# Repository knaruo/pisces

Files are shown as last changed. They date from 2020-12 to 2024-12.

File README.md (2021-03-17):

# pisces
Pisces - Tiny Split Keyboard

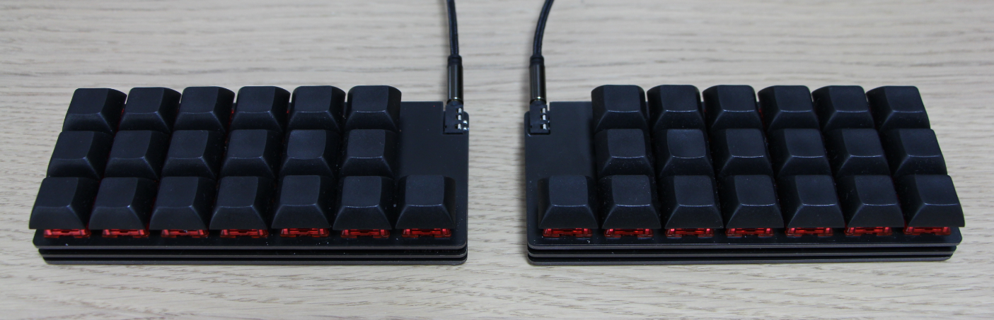
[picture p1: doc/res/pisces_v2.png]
Pisces V1


# Concept

* Ortholinear
  * 3 rows \* 6 columns + 1 thumb key, total 38 keys
* Key switch hot-swap capable
  * Supports Kailh PCB socket for MX
* Thin design
  * Only supports SMT diodes (1N4148W)

# BOM list

Number of components in the following bill of material table is for one hand.

**Here are the mandatory items:**
| Name | Parts id | Number | Note |
| --- | --- | --- | --- |
| Diode | 1N4148W | 19 | Availaable from [here](https://akizukidenshi.com/catalog/g/gI-07084/) |
| ATmega32U2 | - | 1 | |
| TRRS jack | PRT-12639 | 1 | Available from [here](https://www.sengoku.co.jp/mod/sgk_cart/detail.php?code=EEHD-4VML) |
| TRRS cable | - | 1 | |
| Reset Switch | TVAF06-A020B-R | 1 | Available from [here](https://akizukidenshi.com/catalog/g/gP-14888/) |

**For Cherry MX profile:**

| Name | Parts id | Number | Note |
| --- | --- | --- | --- |
| Socket (MX) | CPG151101S11 | 19 | [here](https://kbdfans.com/collections/switches/products/mechanical-keyboard-switches-kailh-pcb-socket) |
| Spacer (M2 7mm)  | ARB-2007E | 6 | [here](https://www.hirosugi-net.co.jp/shop/g/g2392/) |
| Thread (M2 3mm)  | - | 12 | [here for example..](https://www.amazon.co.jp/dp/B083DR1YQL/ref=cm_sw_em_r_mt_dp_sWb6FbA93WCSS) |

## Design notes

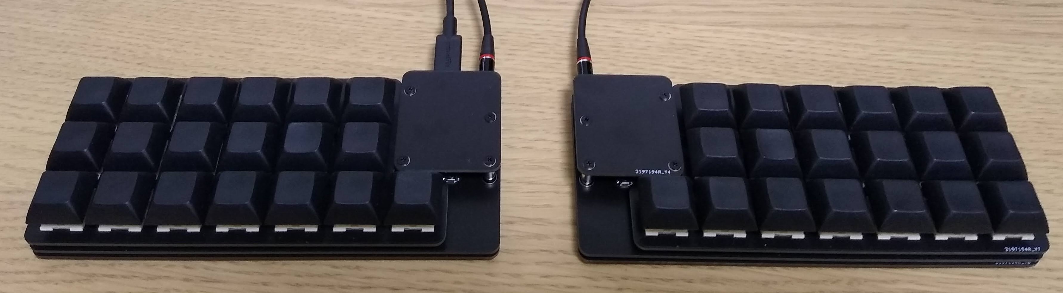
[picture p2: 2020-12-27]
doc/res/pisces_v1_look.jpg

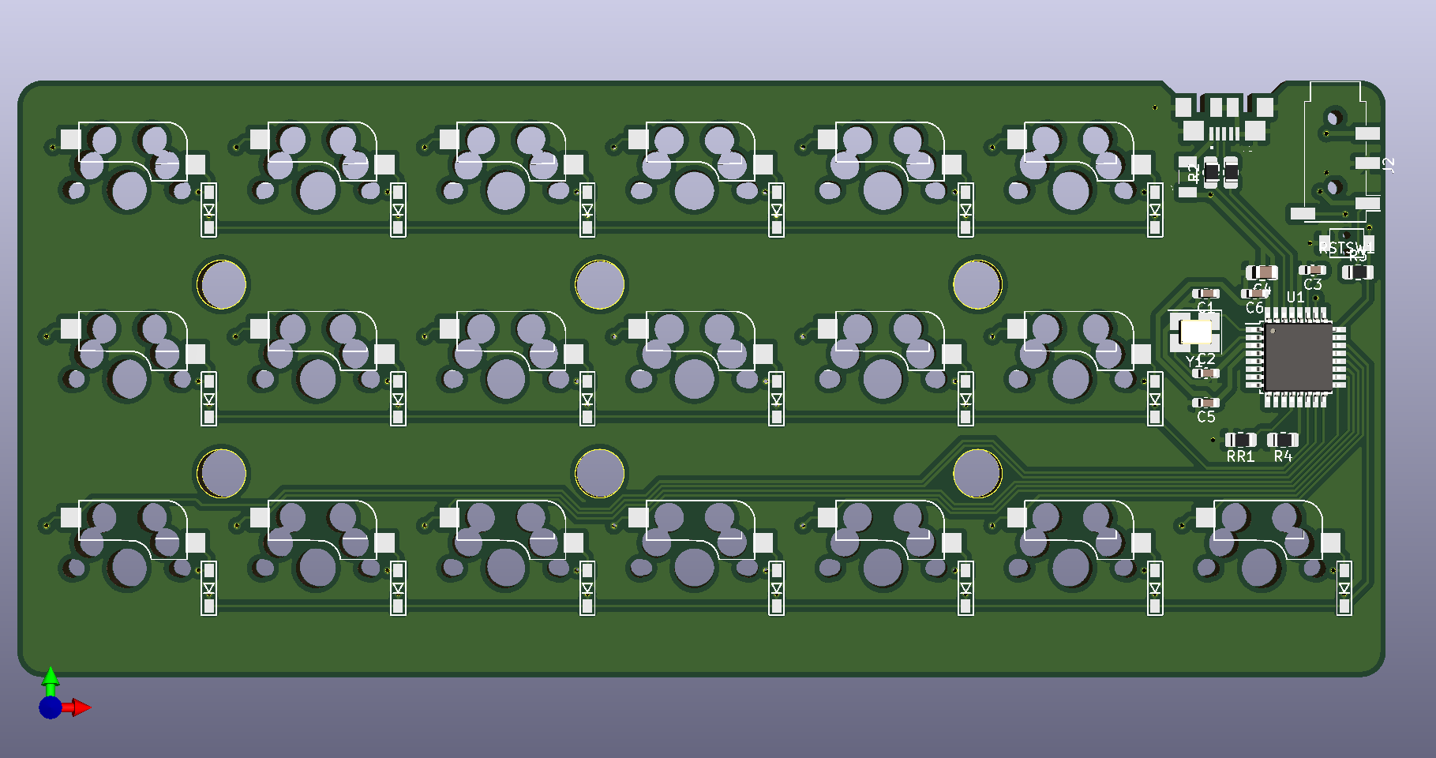
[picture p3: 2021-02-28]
doc/res/pisces_v2_pcb.png

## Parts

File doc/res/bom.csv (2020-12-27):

Name | Parts id | Number | Note
Diode | 1N4148W | 19 | Availaable from [here](https://akizukidenshi.com/catalog/g/gI-07084/)
ProMicro | - | 1 | Available from [here](https://talpkeyboard.stores.jp/items/5b24504ba6e6ee7ec60063e3)
TRRS jack | PRT-12639 | 1 | Available from [here](https://www.sengoku.co.jp/mod/sgk_cart/detail.php?code=EEHD-4VML)
TRRS cable | - | 1
Reset Switch | TVAF06-A020B-R | 1 | Available from [here](https://akizukidenshi.com/catalog/g/gP-14888/)
LED | WS2812B | 1 | Available from [here](https://akizukidenshi.com/catalog/g/gI-07915/)
Socket (MX) | CPG151101S11 | 19 | [here](https://kbdfans.com/collections/switches/products/mechanical-keyboard-switches-kailh-pcb-socket)
Spacer (M2 4mm) | ARB-2004E | 6 | [here](https://www.hirosugi-net.co.jp/shop/g/g2386/)
Spacer (M2 7mm) | ARB-2007E | 6 | [here](https://www.hirosugi-net.co.jp/shop/g/g2392/)
Spacer (M2 12mm) | ARB-2012E | 4 | [here](https://www.hirosugi-net.co.jp/shop/g/g2400/)
Thread (M2 3mm) | - | 20 | [here for example..](https://www.amazon.co.jp/dp/B083DR1YQL/ref=cm_sw_em_r_mt_dp_sWb6FbA93WCSS)
Socket (ChocV1) | CPG135001S30 | 19 | [here](https://kbdfans.com/collections/switches/products/mechanical-keyboard-low-profile-switches-kailh-pcb-socket-cpg135001s30)

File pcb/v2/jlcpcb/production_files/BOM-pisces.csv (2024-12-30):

Comment | Designator | Footprint | LCSC | Quantity
0.1u | C3,C6 | C_0402_1005Metric | C1546 | 2
22p | C1,C2 | C_0402_1005Metric | C1555 | 2
1u | C5 | C_0603_1608Metric | C15849 | 1
10u | C4 | C_0805_2012Metric | C15850 | 1
USB_C | J1 | USB_C_Receptacle_XKB_U262-16XN-4BVC11 | C165948 | 1
5.1k | R1,R2 | R_0603_1608Metric | C23186 | 2
10k | R3,R4 | R_0603_1608Metric | C25804 | 2
5.1k | R5,R6 | R_0402_1005Metric | C25905 | 2
Crystal_GND24_Small | Y1 | Crystal_SMD_SeikoEpson_FA238-4Pin_3.2x2.5mm | C362342 | 1
Polyfuse_Small | F1 | RESC1206X70N | C720075 | 1

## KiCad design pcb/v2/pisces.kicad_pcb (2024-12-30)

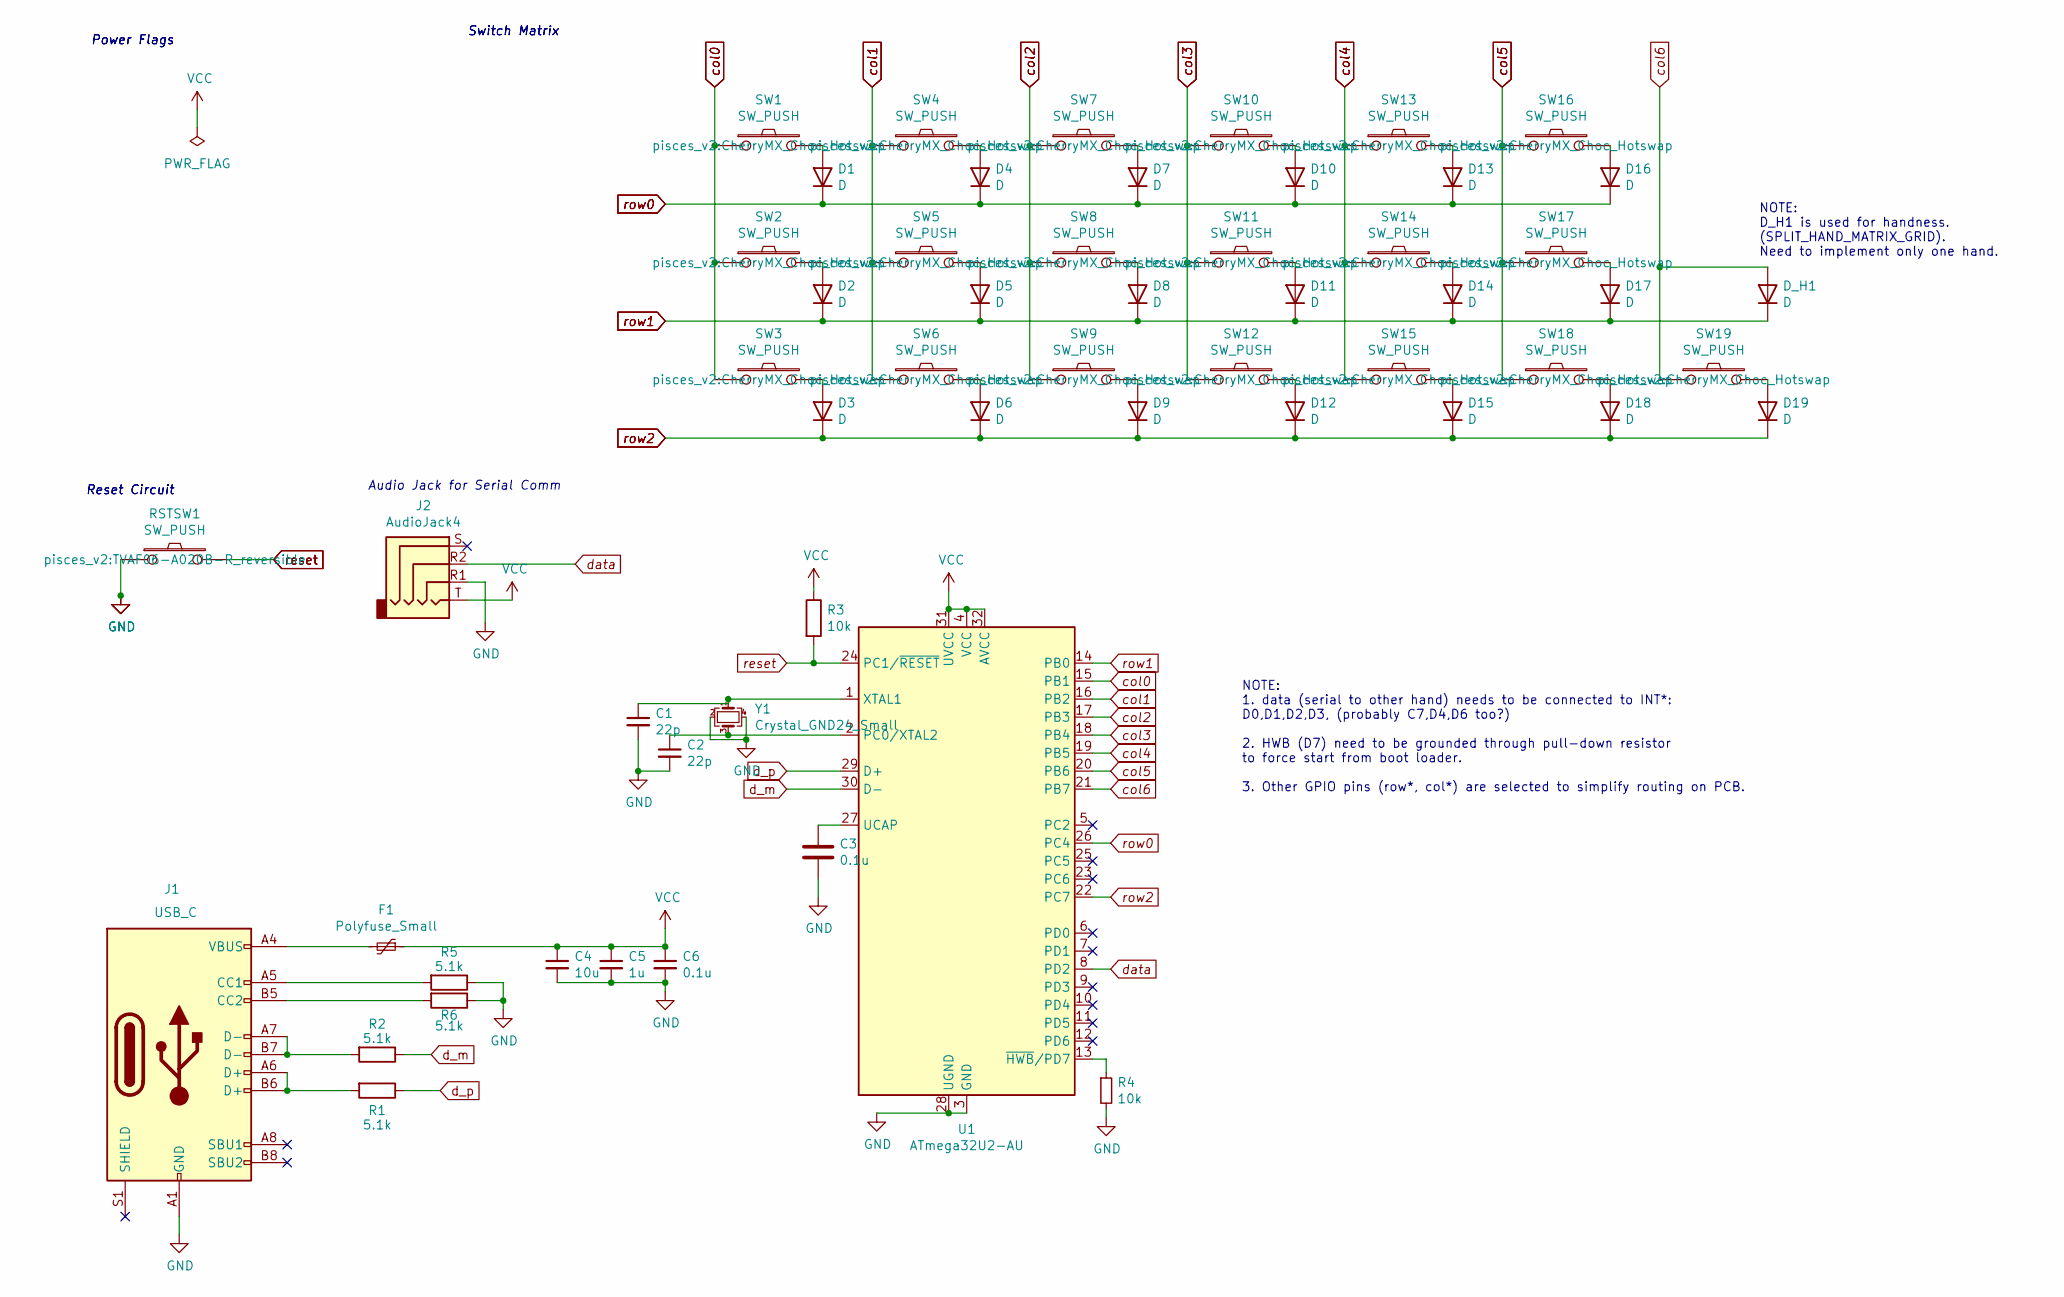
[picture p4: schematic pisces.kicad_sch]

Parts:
C1, C2: 22p; C_0402_1005Metric
C3, C6: 0.1u; C_0402_1005Metric
C4: 10u; C_0805_2012Metric
C5: 1u; C_0603_1608Metric
D1, D2, D3, D4, D5, D6, D7, D8, D9, D10, D11, D12, D13, D14, D15, D16, D17, D18, D19: D; D3_SMD
D_H1: D; D3_SMD
F1: Polyfuse_Small; RESC1206X70N
J1: USB_C; USB_C_Receptacle_XKB_U262-16XN-4BVC11
J2: AudioJack4; Jack_3.5mm_PJ320D_Horizontal_reversible
R1, R2: 5.1k; R_0603_1608Metric
R3, R4: 10k; R_0603_1608Metric
R5, R6: 5.1k; R_0402_1005Metric
RSTSW1: SW_PUSH; TVAF06-A020B-R_reversible
SW1, SW2, SW3, SW4, SW5, SW6, SW7, SW8, SW9, SW10, SW11, SW12, SW13, SW14, SW15, SW16, SW17, SW18, SW19: SW_PUSH; CherryMX_Choc_Hotswap
U1: ATmega32U2-AU; TQFP-32_7x7mm_P0.8mm
Y1: Crystal_GND24_Small; Crystal_SMD_SeikoEpson_FA238-4Pin_3.2x2.5mm

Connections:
GND: C1.2, C2.2, C3.2, C4.2, C5.2, C6.2, J1.A1 (GND), J1.A12 (GND), J1.B1 (GND), J1.B12 (GND), J2.R1, R4.2, R5.1, R6.1, RSTSW1.1, U1.3 (GND), U1.28 (UGND), Y1.2, Y1.4
unnamed: D1.2 (A), SW1.2
unnamed: D2.2 (A), SW2.2
unnamed: D3.2 (A), SW3.2
unnamed: D4.2 (A), SW4.2
unnamed: D5.2 (A), SW5.2
unnamed: D6.2 (A), SW6.2
unnamed: D7.2 (A), SW7.2
unnamed: D8.2 (A), SW8.2
unnamed: D9.2 (A), SW9.2
unnamed: D10.2 (A), SW10.2
unnamed: D11.2 (A), SW11.2
unnamed: D12.2 (A), SW12.2
unnamed: D13.2 (A), SW13.2
unnamed: D14.2 (A), SW14.2
unnamed: D15.2 (A), SW15.2
unnamed: D16.2 (A), SW16.2
unnamed: D17.2 (A), SW17.2
unnamed: D18.2 (A), SW18.2
unnamed: D19.2 (A), SW19.2
unnamed: F1.2, J1.A4 (VBUS), J1.A9 (VBUS), J1.B4 (VBUS), J1.B9 (VBUS)
unnamed: J1.A5 (CC1), R5.2
unnamed: J1.B5 (CC2), R6.2
unnamed: J1.A6 (D+), J1.B6 (D+), R1.2
unnamed: J1.A7 (D-), J1.B7 (D-), R2.2
unnamed: C2.1, U1.2 (PC0/XTAL2), Y1.3
unnamed: C3.1, U1.27 (UCAP)
unnamed: C1.1, U1.1 (XTAL1), Y1.1
unnamed: R4.1, U1.13 (~HWB/PD7)
VCC: C4.1, C5.1, C6.1, F1.1, J2.T, R3.1, U1.4 (VCC), U1.31 (UVCC), U1.32 (AVCC)
col0: SW1.1, SW2.1, SW3.1, U1.15 (PB1)
col1: SW4.1, SW5.1, SW6.1, U1.16 (PB2)
col2: SW7.1, SW8.1, SW9.1, U1.17 (PB3)
col3: SW10.1, SW11.1, SW12.1, U1.18 (PB4)
col4: SW13.1, SW14.1, SW15.1, U1.19 (PB5)
col5: SW16.1, SW17.1, SW18.1, U1.20 (PB6)
col6: D_H1.2 (A), SW19.1, U1.21 (PB7)
d_m: R2.1, U1.30 (D-)
d_p: R1.1, U1.29 (D+)
data: J2.R2, U1.8 (PD2)
reset: R3.2, RSTSW1.2, U1.24 (PC1/~RESET)
row0: D1.1 (K), D4.1 (K), D7.1 (K), D10.1 (K), D13.1 (K), D16.1 (K), U1.26 (PC4)
row1: D2.1 (K), D5.1 (K), D8.1 (K), D11.1 (K), D14.1 (K), D17.1 (K), D_H1.1 (K), U1.14 (PB0)
row2: D3.1 (K), D6.1 (K), D9.1 (K), D12.1 (K), D15.1 (K), D18.1 (K), D19.1 (K), U1.22 (PC7)

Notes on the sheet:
Audio Jack for Serial Comm
Power Flags
Switch Matrix
Reset Circuit
NOTE: D_H1 is used for handness. (SPLIT_HAND_MATRIX_GRID). Need to implement only one hand.
NOTE: 1. data (serial to other hand) needs to be connected to INT*: D0,D1,D2,D3, (probably C7,D4,D6 too?) 2. HWB (D7) need to be grounded through pull-down resistor to force start from boot loader. 3. Other GPIO pins (row*, col*) are selected to simplify routing on PCB.

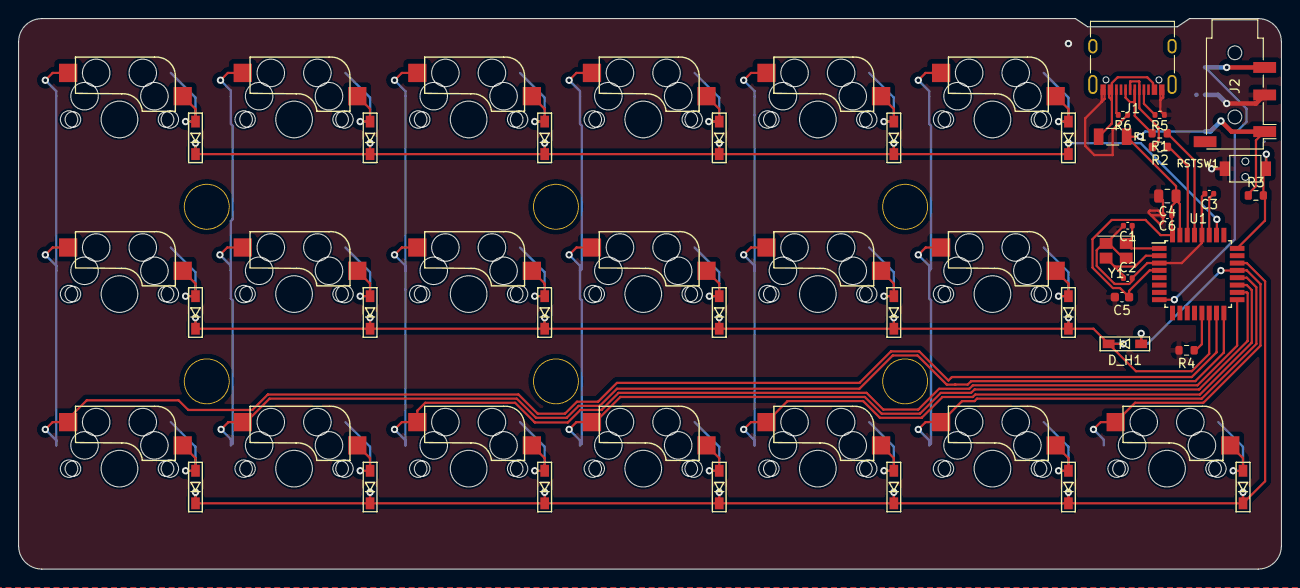
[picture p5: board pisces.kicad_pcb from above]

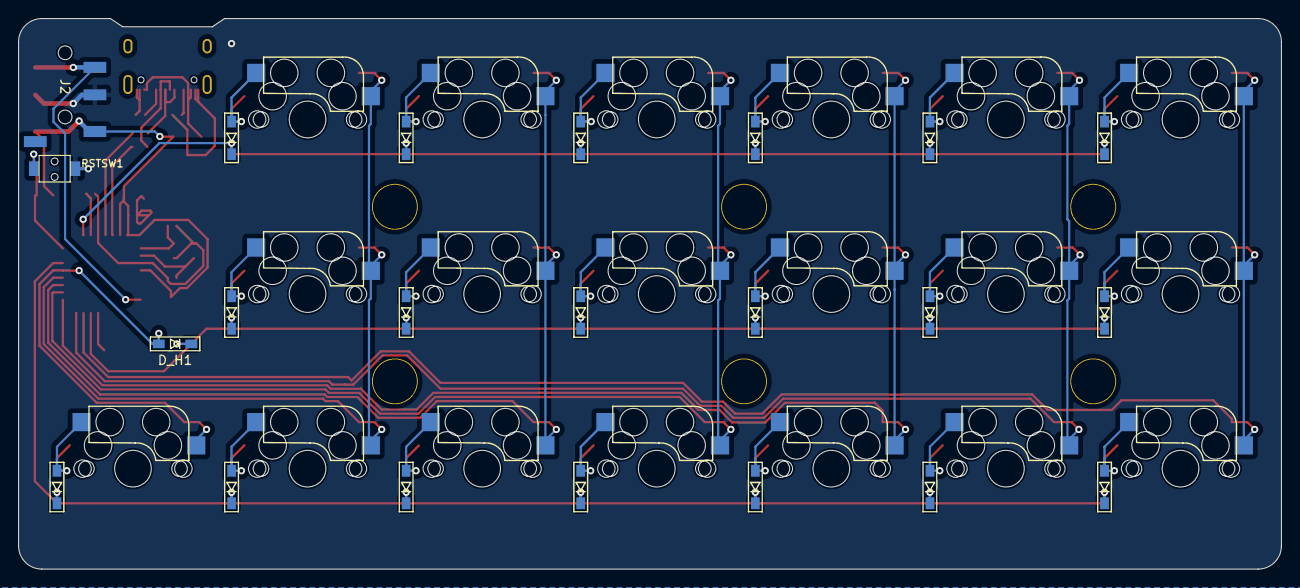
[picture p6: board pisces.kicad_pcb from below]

Board: 2 copper layers, 137.8 x 60.1 mm, 63 parts (19 on the bottom side), 44 nets.

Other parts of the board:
HOLE1, HOLE2, HOLE7, HOLE8, HOLE13, HOLE14: Val**; HOLE

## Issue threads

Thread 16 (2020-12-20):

Fix LED footprint for right-hand side.

knaruo, 2020-12-20:
LED footprint was not correct.

knaruo, 2021-02-28:
Dropped this issue - V1 design is not going to be supported

Closed 2021-02-28.

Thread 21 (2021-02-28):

Fix on V2.0 PCB design

knaruo, 2021-02-28:
- Add terminator resistor to serial comm
- Pull up, pull down resistors to determine right or left hand

knaruo, 2021-03-17:
Done in #22
Pull up/Pull down resistor is not used to determine the handness. Instead, SPLIT_HAND_MATRIX_GRID in QMK feature is used.

Closed 2021-03-17.

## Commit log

2020-12-04 Issue1 copy barracuda (#2)
    * Copied barracuda
    * Generated .net and .kicad_pcb
    * Fixed the switches, diodes, and mounting holes' position
    * Connected row/col/switches tracks
    * Rough Edge.Cut drawing
    * Connected all tracks other than GND
    * almost done with the layout
    [pisces.kicad_pcb, pisces.sch]
2020-12-04 Issue3 add jack (#4)
    * Added a audio jack and connected tracks
    * Filled GND area
    * Aligned mounting holes
    [pisces.kicad_pcb]
2020-12-04 Updated foot prints to reversible (#6)
    [pisces.kicad_pcb]
2020-12-05 Added pisces bottom plate (#8)
    [pisces.kicad_pcb, pisces_bottom_plate.kicad_pcb, pisces_bottom_plate.sch]
2020-12-06 Added top plate (#10)
    [pisces_top_plate.kicad_pcb, pisces_top_plate.sch]
2020-12-06 Added support plate design (#12)
    [pisces_support_plate.kicad_pcb]
2020-12-07 Added generated gerber files for ordering to JLCPCB (#15)
    [pisces-B_Cu.gbr, pisces-B_Mask.gbr, pisces-B_Paste.gbr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]
2020-12-27 Issue17 readme (#18)
    * Added how it looks
    * Added overview
    * Added BOM list
    [bom.csv]
2021-02-28 Issue19 v2 design (#20)
    * draft
    * Done with routing
    * PCB almost there...
    * Added signiture on PCB
    * bottom plate is done
    * done with top plate
    * Pisces V2 ordered PCB with these gerber files
    [pisces-B_Cu.gbr, pisces-B_Mask.gbr, pisces-B_Paste.gbr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]
2021-03-17 Pcb 2.1 op2 (#22)
    * pisces V2.1 option 2 (SPLIT_HAND_MATRIX_GRID)
    * Regenerated pisces pcb gerber files
    [pisces-B_Cu.gbr, pisces-B_Mask.gbr, pisces-B_Paste.gbr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]
2021-03-17 Very quick fix on the README.md to bring PCB2.1 as mainline. (#24)
2024-12-28 Updated KiCad version to 8.0, Supported JLCPCB PCBA info (#27)
    [BOM-pisces.csv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]
2024-12-28 Revert "Updated KiCad version to 8.0, Supported JLCPCB PCBA info (#27)" (#28)
    This reverts commit 94e640e821e110d7bb05b34c9f22027f3d2cd6e9.
    [BOM-pisces.csv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]
2024-12-28 Verified that the current drawing is okay on KiCad 5.1.12 (#29)
    [pisces.sch]
2024-12-28 Removed R5 (resistor) from schematic (#30)
    [pisces.kicad_pcb, pisces.sch]
2024-12-28 Stopped using hand-soldering footprint for most of parts (#31)
    [pisces.kicad_pcb, pisces.sch]
2024-12-28 Used smaller parts footprint (Resistors and Capacitors) (#32)
    * Resistors: 0805 --> 0603, Capacitors (other than 10u): 0603
    * Smaller parts footprint
    [pisces.kicad_pcb, pisces.sch]
2024-12-28 Removed external link to footprint library (#33)
    [pisces.kicad_pcb, pisces.sch]
2024-12-28 KiCad Updated to 6.0.7 (#34)
    [pisces.kicad_pcb, pisces.kicad_sch]
2024-12-29 Updated KiCad 7.0.10 (#35)
    * Removed ERC errors as many as possible
    * symbols も外部依存をなくした
    [pisces.kicad_pcb, pisces.kicad_sch]
2024-12-29 KiCad updated to 8.0.7 (#36)
    [pisces.kicad_pcb, pisces.kicad_sch]
2024-12-29 JLCPCB support (#37)
    [BOM-pisces.csv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]
2024-12-30 Updated USB connector from Micro-B to USB-C (pisces ver 2.2) (#38)
    * USB-C foot printをコピーしてきた
    * USB-C version
    * version should be 2.2
    * Update pisces.kicad_pro
    more exclusion
    [BOM-pisces.csv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]
